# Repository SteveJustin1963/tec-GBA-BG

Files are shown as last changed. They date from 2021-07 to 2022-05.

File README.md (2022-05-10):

# tec-TEC1-Custom-BG
Tec-1 PCB with GBA cartridge system + CPLD  by Ben Grimmett
- see also https://github.com/SteveJustin1963/tec-CPLD-BG

### features
- TEC ROM/RAM card 
- 4mbytes banked Flash
- 32 kbytes Banked NVRAM
- Just a suggestion for a proven, cheap, robust, plentiful supply of hot swappable memory cards for a future TEC-1.

### Memory map:
```
0x0000-3FFF fixed to Flash Address 0x0000-3FFF
0x4000-7FFF 256 banks, can be swapped by writing to address 0x2000.
0xA000-BFFF 8kbytes of NVRAM.
```
- Write protected unless `0x0A` written to `0x0000`. Protected if any other value is written to that address. 
- Bank swapped by writing to `0x4000`

This still gives you empty spots in the memory map for other things, and the entire cart can be disabled with a /CS signal, or just unplugged. These are common bootleg GameBoy Cartridges. Z80-like code executes directly from them in the GB. You can find them on eBay or aliexpress from $4 shipped to your door.

### How do you get code on them? 
You can do it in system, or use any number of GB Cart flashers like the pic included. The cart appears as a USB mass storage drive, you drag the firmware on, and its done. Not sure you can beat the bang for buck these offer. Cart sockets are $1 ea and with HUGE pins, soldering won't be a problem.

### buy from Benn (Goulburn NSW):
- 4Mbyte Flash + 32K save (volatile) - https://bennvenn.myshopify.com/.../gb-c-flash-cart-4mbyte...
- 4Mbyte + 32K battery backed (NV) - https://bennvenn.myshopify.com/.../gb-c-flash-cart-4mbyte...
- The best cart flasher you can buy! (USB Drag and drop, no drivers, no software) - https://bennvenn.myshopify.com/.../usb-gb-c-cart-dumper...
- Cart Sockets: https://bennvenn.myshopify.com/.../32pin-gb-c-a-cart...
- https://bennvenn.myshopify.com/products/usb-gb-c-cart-dumper-the-joey-jr

### slowboat from china:
- 4M + 32K NV - https://www.aliexpress.com/item/4000589108517.html...
AVOID CHINESE FLASHERS - they're all clones of ours or others and have adopted the nickname 'firestarters' for a good reason. A cheaper flasher is the GBxRW from Inside Gadgets. Another Aussie company. A little slower, a little more clunky but you'll save $10 or so, they don't support some chinese carts.
Chinese cart socket - https://www.aliexpress.com/item/4001322498055.html...

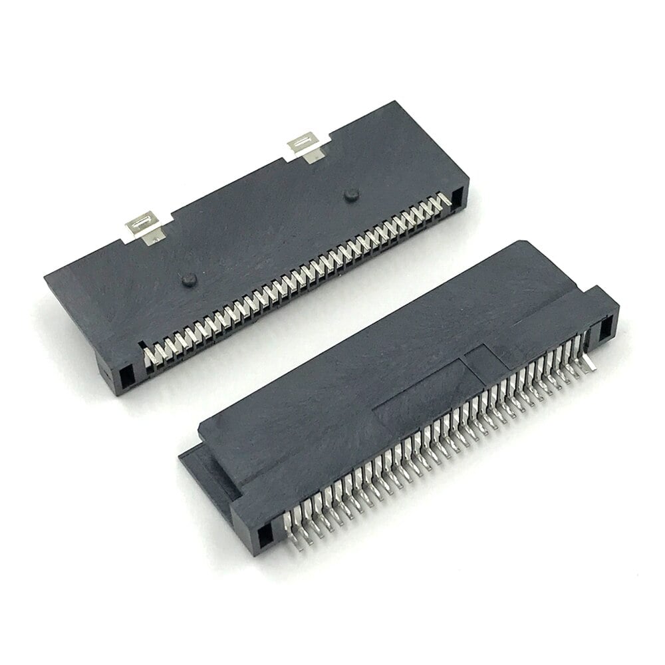
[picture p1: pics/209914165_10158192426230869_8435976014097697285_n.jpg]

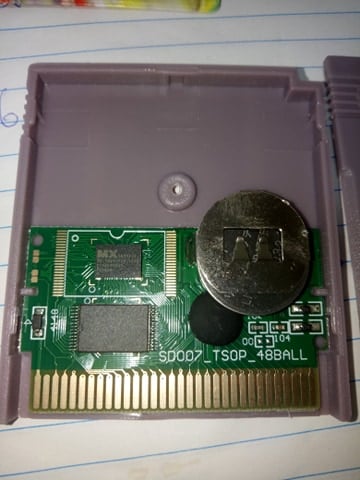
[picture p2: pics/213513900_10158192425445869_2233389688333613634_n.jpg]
 
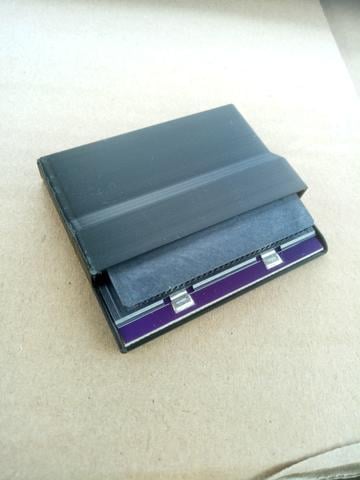
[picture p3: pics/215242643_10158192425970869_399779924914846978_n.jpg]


### BG; Finished!
```
0x0000-07FF EPROM
0x0800-0FFF SRAM
0x1000-17FF expansion dip
0x4000-7FFF 4mbytes of flash
0xA000-BFFF 32kbytes nvram
```
### features
- Reproduced the keypad IC in VHDL with debounce filtering.
- Errors: silkscreen Rom and ram locations are swapped. 
- Fixed in CPLD but a wr wire added. If I didn't solder the sram in I could have swapped sockets.
- Keypad matrix pull-ups needed, the max3000 family of CPLD don't support internal pull-ups. 
- Fitted in the column pads instead. Could use a network resistor for a neater finish.
- And jtag #2 and jtag #3 ports are swapped.
- Need to add resistors to satisfy MonB code or fix the routine.
- Can execute code from gameboy cart!
- 4 PCBs up for grabs. $25plus post and I'll solder in the CPLDs and 3.3v reg and flash the code to them.  

### info

The TEC-1 is a tec-compatible computer with a GB (Game Boy) cart slot to make use of a GB carts huge ROM and nvRAM capacity. It won't play GB games. The idea behind this is to help you learn how to code CPLD's. BG; I don't have that many spare Z80's or other bits and pieces for full kits. They will include the CPLD's though, pre soldered and programmed. A cpld is a fpga, just a different name (and other differences). Programming needs a $10 usb programmer from ebay (USB Blaster). As for the code, you can use the visual designer where you just drag logic chips and draw wires, or you can code in a specific language. I'll upload all the code here.

Using a CPLD for address decoding for example means you can fully reconfigure the memory map in seconds and it doesn't have the same issues the original TEC did with address decoding. You can also change how the 7seg driver works, the TEC must constantly refresh the LED's, you *could* code a driver in the CPLD to do that for you to free up the z80 for more important things. And finally, the keypad CPLD - it emulates the original chip but it can also be expanded to hundreds of keys, or even a ps2 keyboard.

Can a FPGA be made to emulate a 74C923? If so, can you get FPGAs in 20 pin DIP (or SOIC) packages ? Yes, the second CPLD on the board emulates the '923 and heaps of room to spare. I've got some dip PCBs coming in a week that'll convert the qfp package to dip 28. The circuit will be upload.

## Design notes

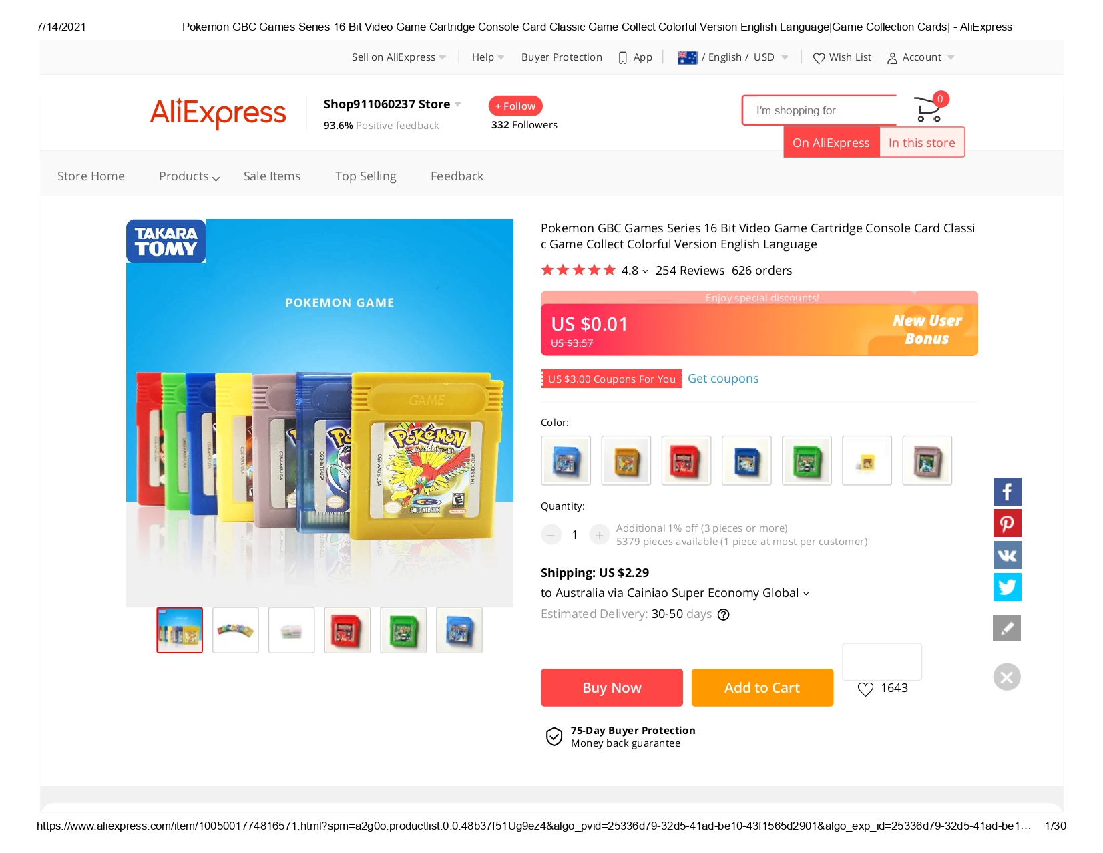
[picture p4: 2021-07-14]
pics/Pokemon GBC Games Series 16 Bit Video Game Cartridge Console Card Classic Game Collect Colorful Version English Language_Game Collection Cards_ - AliExpress_page-0001.jpg

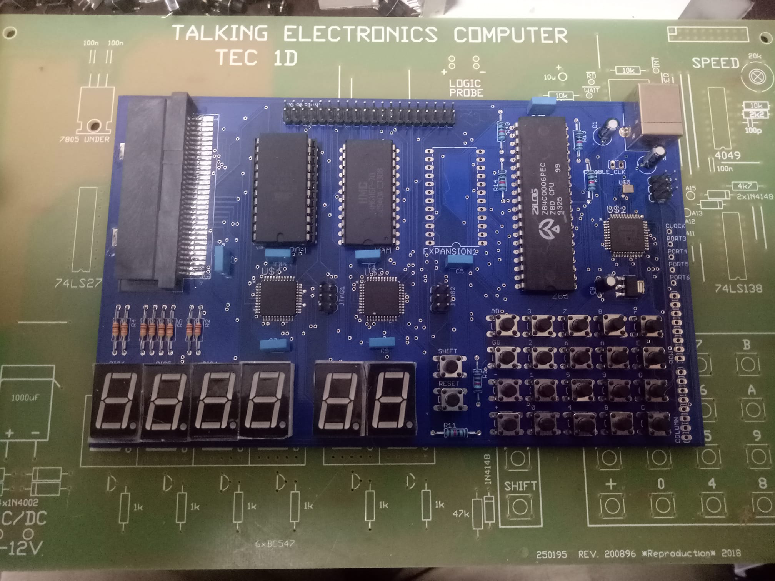
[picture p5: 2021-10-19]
pics/241389135_10158286503960869_3780352322921528001_n.jpg

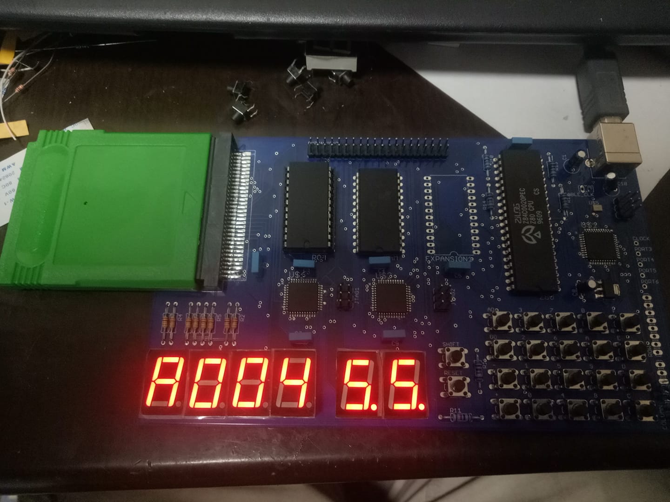
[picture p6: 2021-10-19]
pics/241639993_10158287111470869_8258632653021072669_n.jpg

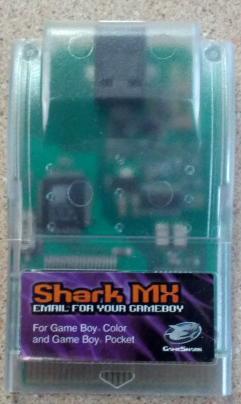
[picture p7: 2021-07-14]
pics/214411736_10158192478090869_7950355688786903180_n.jpg

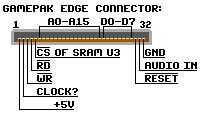
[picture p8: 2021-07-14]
pics/216936971_10158192456405869_8650335024998492542_n.jpg

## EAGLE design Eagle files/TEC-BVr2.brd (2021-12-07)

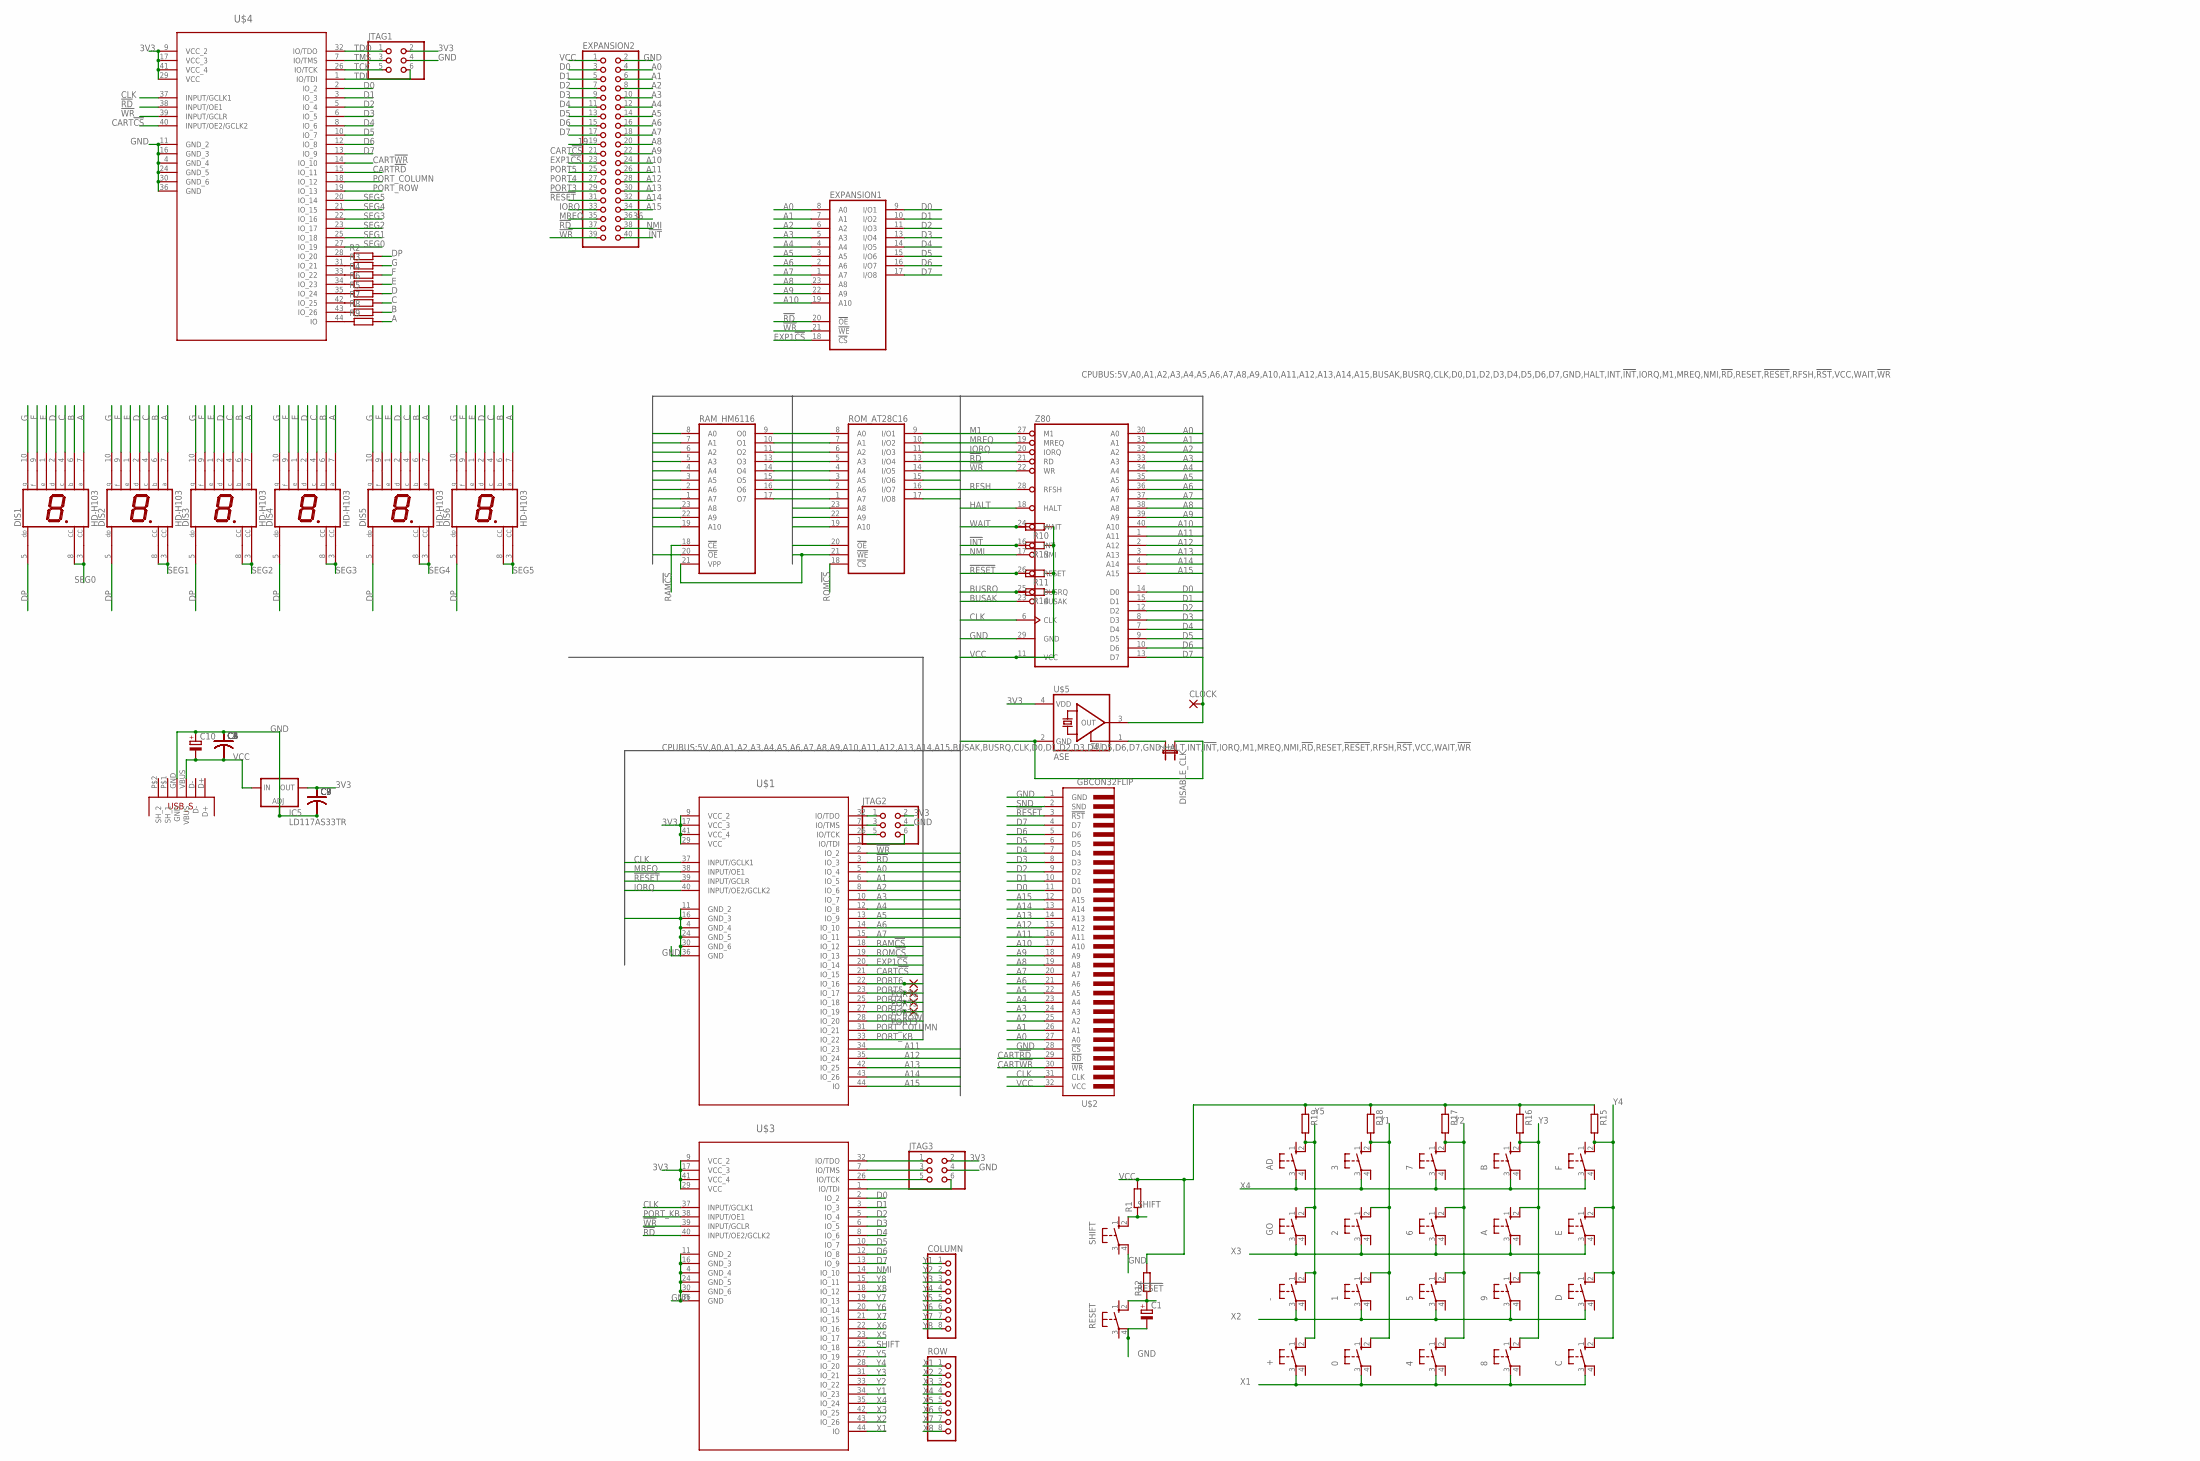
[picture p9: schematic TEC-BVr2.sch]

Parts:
0, 1, 2, 3, 4, 5, 6, 7, 8, 9: 10-XX; B3F-10XX
+: 10-XX; B3F-10XX
-: 10-XX; B3F-10XX
A: 10-XX; B3F-10XX
AD: 10-XX; B3F-10XX
B: 10-XX; B3F-10XX
C: 10-XX; B3F-10XX
C1, C10: CPOL-EUE2,5-6E; E2,5-6E
C2, C3, C4, C5, C6, C7, C8, C9: C-US050-024X044; C050-024X044
CLOCK: 1,6/0,8
COLUMN: PINHD-1X8; 1X08
D: 10-XX; B3F-10XX
DIS1, DIS2, DIS3, DIS4, DIS5, DIS6: HD-H103; HDSP-M
DISABLE_CLK: JP1E; JP1
E: 10-XX; B3F-10XX
EXPANSION1: 6116P; DIL24-6
EXPANSION2: PINHD-2X20; 2X20
F: 10-XX; B3F-10XX
GO: 10-XX; B3F-10XX
IC5: LD117AS33TR; SOT223
JTAG1, JTAG2, JTAG3: PINHD-2X3; 2X03
PORT3, PORT4, PORT5, PORT6: 1,6/0,8
R1, R2, R3, R4, R5, R6, R7, R8, R9, R10, R11, R12, R13, R14: R-EU_0207/12; 0207/12
R15, R16, R17, R18, R19: R-EU_0204/7; 0204/7
RAM_HM6116: 2716; DIL24
RESET: 10-XX; B3F-10XX
ROM_AT28C16: 6116P; DIL24-6
ROW: PINHD-1X8; 1X08
SHIFT: 10-XX; B3F-10XX
U$1: Address Decoding; QFP80P1200X1200X120-44N
U$2: GBCON32FLIP; GB_CON32
U$3: Keyboard Decoding; QFP80P1200X1200X120-44N
U$4: Display Decoding; QFP80P1200X1200X120-44N
U$5: ASE
U$6: USB; USB_B_PTH
Z80: Z80CPU; DIL40

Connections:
3V3: C7.1, C8.1, C9.1, IC5.4 (OUT), JTAG1.2, JTAG2.2, JTAG3.2, U$1.9 (VCC_2), U$1.17 (VCC_3), U$1.29 (VCC), U$1.41 (VCC_4), U$3.9 (VCC_2), U$3.17 (VCC_3), U$3.29 (VCC), U$3.41 (VCC_4), U$4.9 (VCC_2), U$4.17 (VCC_3), U$4.29 (VCC), U$4.41 (VCC_4), U$5.4 (VDD)
19: EXPANSION2.19
36: EXPANSION2.36
!INT: EXPANSION2.40, R13.2, Z80.16 (INT)
!RD: EXPANSION1.20 (!OE), EXPANSION2.37, RAM_HM6116.20 (!OE), ROM_AT28C16.20 (!OE), U$1.3 (IO_3), U$3.40 (INPUT/OE2/GCLK2), U$4.38 (INPUT/OE1), Z80.21 (RD)
!RESET: C1.+, EXPANSION2.31, R11.2, R12.1, RESET.2 (S1), U$1.39 (INPUT/GCLR), U$2.3 (!RST), Z80.26 (RESET)
!WR: EXPANSION1.21 (!WE), EXPANSION2.39, RAM_HM6116.21 (VPP), ROM_AT28C16.21 (!WE), U$1.2 (IO_2), U$3.39 (INPUT/GCLR), U$4.39 (INPUT/GCLR), Z80.22 (WR)
A: DIS1.7 (A), DIS2.7 (A), DIS3.7 (A), DIS4.7 (A), DIS5.7 (A), DIS6.7 (A), R9.2
A0: EXPANSION1.8 (A0), EXPANSION2.4, RAM_HM6116.8 (A0), ROM_AT28C16.8 (A0), U$1.5 (IO_4), U$2.27 (A0), Z80.30 (A0)
A1: EXPANSION1.7 (A1), EXPANSION2.6, RAM_HM6116.7 (A1), ROM_AT28C16.7 (A1), U$1.6 (IO_5), U$2.26 (A1), Z80.31 (A1)
A2: EXPANSION1.6 (A2), EXPANSION2.8, RAM_HM6116.6 (A2), ROM_AT28C16.6 (A2), U$1.8 (IO_6), U$2.25 (A2), Z80.32 (A2)
A3: EXPANSION1.5 (A3), EXPANSION2.10, RAM_HM6116.5 (A3), ROM_AT28C16.5 (A3), U$1.10 (IO_7), U$2.24 (A3), Z80.33 (A3)
A4: EXPANSION1.4 (A4), EXPANSION2.12, RAM_HM6116.4 (A4), ROM_AT28C16.4 (A4), U$1.12 (IO_8), U$2.23 (A4), Z80.34 (A4)
A5: EXPANSION1.3 (A5), EXPANSION2.14, RAM_HM6116.3 (A5), ROM_AT28C16.3 (A5), U$1.13 (IO_9), U$2.22 (A5), Z80.35 (A5)
A6: EXPANSION1.2 (A6), EXPANSION2.16, RAM_HM6116.2 (A6), ROM_AT28C16.2 (A6), U$1.14 (IO_10), U$2.21 (A6), Z80.36 (A6)
A7: EXPANSION1.1 (A7), EXPANSION2.18, RAM_HM6116.1 (A7), ROM_AT28C16.1 (A7), U$1.15 (IO_11), U$2.20 (A7), Z80.37 (A7)
A8: EXPANSION1.23 (A8), EXPANSION2.20, RAM_HM6116.23 (A8), ROM_AT28C16.23 (A8), U$2.19 (A8), Z80.38 (A8)
A9: EXPANSION1.22 (A9), EXPANSION2.22, RAM_HM6116.22 (A9), ROM_AT28C16.22 (A9), U$2.18 (A9), Z80.39 (A9)
A10: EXPANSION1.19 (A10), EXPANSION2.24, RAM_HM6116.19 (A10), ROM_AT28C16.19 (A10), U$2.17 (A10), Z80.40 (A10)
A11: EXPANSION2.26, U$1.34 (IO_23), U$2.16 (A11), Z80.1 (A11)
A12: EXPANSION2.28, U$1.35 (IO_24), U$2.15 (A12), Z80.2 (A12)
A13: EXPANSION2.30, U$1.42 (IO_25), U$2.14 (A13), Z80.3 (A13)
A14: EXPANSION2.32, U$1.43 (IO_26), U$2.13 (A14), Z80.4 (A14)
A15: EXPANSION2.34, U$1.44 (IO), U$2.12 (A15), Z80.5 (A15)
B: DIS1.6 (B), DIS2.6 (B), DIS3.6 (B), DIS4.6 (B), DIS5.6 (B), DIS6.6 (B), R8.2
BUSAK: Z80.23 (BUSAK)
BUSRQ: R14.2, Z80.25 (BUSRQ)
C: DIS1.4 (C), DIS2.4 (C), DIS3.4 (C), DIS4.4 (C), DIS5.4 (C), DIS6.4 (C), R7.2
CART!CS: EXPANSION2.21, U$1.21 (IO_15), U$4.40 (INPUT/OE2/GCLK2)
CART!RD: U$2.29 (!RD), U$4.15 (IO_11)
CART!WR: U$2.30 (!WR), U$4.14 (IO_10)
CLK: CLOCK.1, U$1.37 (INPUT/GCLK1), U$2.31 (CLK), U$3.37 (INPUT/GCLK1), U$4.37 (INPUT/GCLK1), U$5.3 (OUT), Z80.6 (CLK)
D: DIS1.2 (D), DIS2.2 (D), DIS3.2 (D), DIS4.2 (D), DIS5.2 (D), DIS6.2 (D), R5.2
D0: EXPANSION1.9 (I/O1), EXPANSION2.3, RAM_HM6116.9 (O0), ROM_AT28C16.9 (I/O1), U$2.11 (D0), U$3.2 (IO_2), U$4.2 (IO_2), Z80.14 (D0)
D1: EXPANSION1.10 (I/O2), EXPANSION2.5, RAM_HM6116.10 (O1), ROM_AT28C16.10 (I/O2), U$2.10 (D1), U$3.3 (IO_3), U$4.3 (IO_3), Z80.15 (D1)
D2: EXPANSION1.11 (I/O3), EXPANSION2.7, RAM_HM6116.11 (O2), ROM_AT28C16.11 (I/O3), U$2.9 (D2), U$3.5 (IO_4), U$4.5 (IO_4), Z80.12 (D2)
D3: EXPANSION1.13 (I/O4), EXPANSION2.9, RAM_HM6116.13 (O3), ROM_AT28C16.13 (I/O4), U$2.8 (D3), U$3.6 (IO_5), U$4.6 (IO_5), Z80.8 (D3)
D4: EXPANSION1.14 (I/O5), EXPANSION2.11, RAM_HM6116.14 (O4), ROM_AT28C16.14 (I/O5), U$2.7 (D4), U$3.8 (IO_6), U$4.8 (IO_6), Z80.7 (D4)
D5: EXPANSION1.15 (I/O6), EXPANSION2.13, RAM_HM6116.15 (O5), ROM_AT28C16.15 (I/O6), U$2.6 (D5), U$3.10 (IO_7), U$4.10 (IO_7), Z80.9 (D5)
D6: EXPANSION1.16 (I/O7), EXPANSION2.15, RAM_HM6116.16 (O6), ROM_AT28C16.16 (I/O7), U$2.5 (D6), U$3.12 (IO_8), U$4.12 (IO_8), Z80.10 (D6)
D7: EXPANSION1.17 (I/O8), EXPANSION2.17, RAM_HM6116.17 (O7), ROM_AT28C16.17 (I/O8), U$2.4 (D7), U$3.13 (IO_9), U$4.13 (IO_9), Z80.13 (D7)
DP: DIS1.5 (DP), DIS2.5 (DP), DIS3.5 (DP), DIS4.5 (DP), DIS5.5 (DP), DIS6.5 (DP), R2.2
E: DIS1.1 (E), DIS2.1 (E), DIS3.1 (E), DIS4.1 (E), DIS5.1 (E), DIS6.1 (E), R6.2
EXP1!CS: EXPANSION1.18 (!CS), EXPANSION2.23, U$1.20 (IO_14)
F: DIS1.9 (F), DIS2.9 (F), DIS3.9 (F), DIS4.9 (F), DIS5.9 (F), DIS6.9 (F), R4.2
G: DIS1.10 (G), DIS2.10 (G), DIS3.10 (G), DIS4.10 (G), DIS5.10 (G), DIS6.10 (G), R3.2
GND: C1.-, C2.1, C3.1, C4.1, C5.1, C6.1, C7.2, C8.2, C9.2, C10.+, DISABLE_CLK.1, EXPANSION1.12 (GND), EXPANSION2.2, IC5.1 (ADJ), JTAG1.4, JTAG2.4, JTAG3.4, RAM_HM6116.12 (GND), RESET.4 (P1), ROM_AT28C16.12 (GND), SHIFT.4 (P1), U$1.4 (GND_4), U$1.11 (GND_2), U$1.16 (GND_3), U$1.24 (GND_5), U$1.30 (GND_6), U$1.36 (GND), U$2.1 (GND), U$2.28 (!CS), U$3.4 (GND_4), U$3.11 (GND_2), U$3.16 (GND_3), U$3.24 (GND_5), U$3.30 (GND_6), U$3.36 (GND), U$4.4 (GND_4), U$4.11 (GND_2), U$4.16 (GND_3), U$4.24 (GND_5), U$4.30 (GND_6), U$4.36 (GND), U$5.2 (GND), U$6.GND, Z80.29 (GND)
HALT: Z80.18 (HALT)
IORQ: EXPANSION2.33, U$1.40 (INPUT/OE2/GCLK2), Z80.20 (IORQ)
M1: Z80.27 (M1)
MREQ: EXPANSION2.35, U$1.38 (INPUT/OE1), Z80.19 (MREQ)
unnamed: R2.1, U$4.28 (IO_20)
unnamed: R3.1, U$4.31 (IO_21)
unnamed: R4.1, U$4.33 (IO_22)
unnamed: R5.1, U$4.35 (IO_24)
unnamed: JTAG3.1, U$3.32 (IO/TDO)
unnamed: DISABLE_CLK.2, U$5.1 (TRI)
unnamed: JTAG3.3, U$3.7 (IO/TMS)
unnamed: R6.1, U$4.34 (IO_23)
unnamed: R7.1, U$4.42 (IO_25)
unnamed: R8.1, U$4.43 (IO_26)
unnamed: R9.1, U$4.44 (IO)
unnamed: JTAG3.5, U$3.26 (IO/TCK)
unnamed: JTAG3.6, U$3.1 (IO/TDI)
unnamed: JTAG2.1, U$1.32 (IO/TDO)
unnamed: JTAG2.3, U$1.7 (IO/TMS)
unnamed: JTAG2.5, U$1.26 (IO/TCK)
unnamed: JTAG2.6, U$1.1 (IO/TDI)
NMI: EXPANSION2.38, U$3.14 (IO_10), Z80.17 (NMI)
PORT3: EXPANSION2.29, PORT3.1, U$1.27 (IO_19)
PORT4: EXPANSION2.27, PORT4.1, U$1.25 (IO_18)
PORT5: EXPANSION2.25, PORT5.1, U$1.23 (IO_17)
PORT6: PORT6.1, U$1.22 (IO_16)
PORT_COLUMN: U$1.31 (IO_21), U$4.18 (IO_12)
PORT_KB: U$1.33 (IO_22), U$3.38 (INPUT/OE1)
PORT_ROW: U$1.28 (IO_20), U$4.19 (IO_13)
RAM!CS: RAM_HM6116.18 (!CE), U$1.18 (IO_12)
RFSH: Z80.28 (RFSH)
ROM!CS: ROM_AT28C16.18 (!CS), U$1.19 (IO_13)
SEG0: DIS1.3 (CC), DIS1.8 (CC), U$4.27 (IO_19)
SEG1: DIS2.3 (CC), DIS2.8 (CC), U$4.25 (IO_18)
SEG2: DIS3.3 (CC), DIS3.8 (CC), U$4.23 (IO_17)
SEG3: DIS4.3 (CC), DIS4.8 (CC), U$4.22 (IO_16)
SEG4: DIS5.3 (CC), DIS5.8 (CC), U$4.21 (IO_15)
SEG5: DIS6.3 (CC), DIS6.8 (CC), U$4.20 (IO_14)
SHIFT: R1.1, SHIFT.2 (S1), U$3.25 (IO_18)
SND: U$2.2 (SND)
TCK: JTAG1.5, U$4.26 (IO/TCK)
TDI: JTAG1.6, U$4.1 (IO/TDI)
TDO: JTAG1.1, U$4.32 (IO/TDO)
TMS: JTAG1.3, U$4.7 (IO/TMS)
VCC: C2.2, C3.2, C4.2, C5.2, C6.2, C10.-, EXPANSION1.24 (VCC), EXPANSION2.1, IC5.3 (IN), R1.2, R10.1, R11.1, R12.2, R13.1, R14.1, R15.1, R16.1, R17.1, R18.1, R19.1, RAM_HM6116.24 (VCC), ROM_AT28C16.24 (VCC), U$2.32 (VCC), U$6.VBUS, Z80.11 (VCC)
WAIT: R10.2, Z80.24 (WAIT)
X1: 0.3, 4.3, 8.3, +.3, C.3, ROW.1, U$3.44 (IO)
X2: 1.3, 5.3, 9.3, -.3, D.3, ROW.2, U$3.43 (IO_26)
X3: 2.3, 6.3, A.3, E.3, GO.3, ROW.3, U$3.42 (IO_25)
X4: 3.3, 7.3, AD.3, B.3, F.3, ROW.4, U$3.35 (IO_24)
X5: ROW.5, U$3.23 (IO_17)
X6: ROW.6, U$3.22 (IO_16)
X7: ROW.7, U$3.21 (IO_15)
X8: ROW.8, U$3.18 (IO_12)
Y1: 0.2 (S1), 1.2 (S1), 2.2 (S1), 3.2 (S1), COLUMN.1, R18.2, U$3.34 (IO_23)
Y2: 4.2 (S1), 5.2 (S1), 6.2 (S1), 7.2 (S1), COLUMN.2, R17.2, U$3.33 (IO_22)
Y3: 8.2 (S1), 9.2 (S1), A.2 (S1), B.2 (S1), COLUMN.3, R16.2, U$3.31 (IO_21)
Y4: C.2 (S1), COLUMN.4, D.2 (S1), E.2 (S1), F.2 (S1), R15.2, U$3.28 (IO_20)
Y5: +.2 (S1), -.2 (S1), AD.2 (S1), COLUMN.5, GO.2 (S1), R19.2, U$3.27 (IO_19)
Y6: COLUMN.6, U$3.20 (IO_14)
Y7: COLUMN.7, U$3.19 (IO_13)
Y8: COLUMN.8, U$3.15 (IO_11)

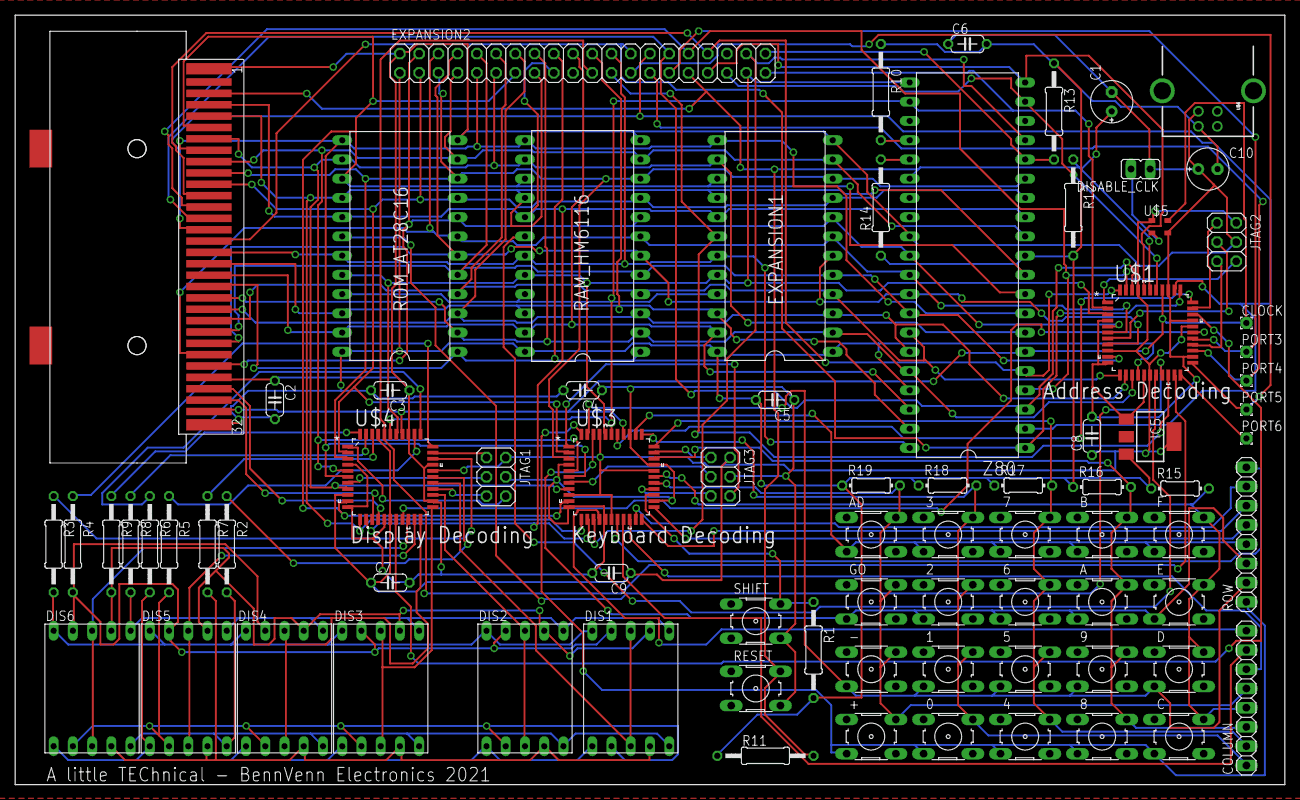
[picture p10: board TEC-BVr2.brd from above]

Board: 2 copper layers, 167.6 x 101.6 mm, 80 parts (0 on the bottom side), 102 nets.
